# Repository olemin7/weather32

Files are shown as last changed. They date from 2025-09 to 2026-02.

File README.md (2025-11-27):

weather stantion
redused CPU frequency to 80
# Troubleshooting

* Program upload failure

    * Hardware connection is not correct: run `idf.py -p PORT monitor`, and reboot your board to see if there are any output logs.
    * The baud rate for downloading is too high: lower your baud rate in the `menuconfig` menu, and try again.

https://esp-idf-lib.readthedocs.io/en/latest/groups/bmp180.html

https://github.com/espressif/esp-iot-solution

# esp32c3_supermini
    Pin     | ADC | func |
GPIO_NUM_0  | A0  |      |photoresistor
GPIO_NUM_1  | A1  |      |service switch
GPIO_NUM_2  | A2  |      |
GPIO_NUM_3  | A3  |      |
GPIO_NUM_4  | A4  | SCK  | 
3V3
GND
5V
-------------------------------------
GPIO_NUM_5  | A5  | MISO |
GPIO_NUM_6  |     | MOSI | bme680 SDA !!! swap in new PCB version
GPIO_NUM_7  |     | SS   | bme680 SDL
GPIO_NUM_8  |     | SDA  | LED           
GPIO_NUM_9  |     | SDL  | BOOT_BUTTON   
GPIO_NUM_10 |     |      |
GPIO_NUM_20 |     | RX   |
GPIO_NUM_21 |     | TX   |

https://github.com/DiegoPaezA/ESP32-freeRTOS/blob/master/i2c_scanner/main/i2c_scanner.c
https://github.com/espressif/esp-iot-solution/tree/dd15770d0f8c5fedea78809737f04b63d3765c83/examples/sensors/sensor_hub_monitor

. /home/oleksandr/ides/tools/esp-idf-v5.3/export.sh
export IOT_SOLUTION_PATH=/home/oleksandr/personal/repo/esp-iot-solution
idf.py set-target esp32c3
idf.py build
idf.py menuconfig

null in the env https://github.com/espressif/idf-eclipse-plugin/issues/535https://components.espressif.com/

Check the values in your sdkconfig for LOG_MAXIMUM_LEVEL. It defaults to matching LOG_DEFAULT_LEVEL which limits what values you can use by default.

# mqtt test
sudo apt-get install mosquitto mosquitto-clients

sudo vim /etc/mosquitto/mosquitto.conf 
add
  listener 1883 0.0.0.0
  allow_anonymous true

sudo ufw allow 1883

sudo /etc/init.d/mosquitto restart

mosquitto_sub -h nas.local -d -t advertisement
mosquitto_pub -h nas.local -d -t cmd -m "adv"
mosquitto_sub -h 192.168.1.2 -d -t devices/64E833880880/#

one terminal
mosquitto_sub -d -t hello/world
mosquitto_sub -d -t stat/weather -h central.local
Connect to another ssh session and run
mosquitto_pub -d -t hello/world -m "Hello from terminal window 2!"

sudo tail -f /var/log/mosquitto/mosquitto.log

mosquitto_sub -h nas.local -d -t '#'
https://github.com/nopnop2002/esp-idf-json/tree/master/json-basic-object

# button
todo boot btn to go provision mode?

# esp-idf-lib
https://esp-idf-lib.readthedocs.io/en/latest/index.html
git clone git@github.com:UncleRus/esp-idf-lib.git

# dependency
https://github.com/olemin7/esp32_idf_libs

# TP4056  li ion charger
max 4.2
min 2.5
## li ion
max 4.2
min 3.0

## attenuation
ADC_ATTEN_DB_0   100 mV ~ 950 mV
ADC_ATTEN_DB_2_5 100 mV ~ 1250 mV
ADC_ATTEN_DB_6   150 mV ~ 1750 mV
ADC_ATTEN_DB_12  150 mV ~ 2450 mV

https://docs.espressif.com/projects/esp-idf/en/v4.4.8/esp32/api-reference/peripherals/adc.html
#photoresistor (GND ) -photoresistor- (A0) -resistor 10k- (+3.3)

# LiIon
min 
https://esp32tutorials.com/esp32-esp-idf-max7219-dot-matrix-display

[json]
https://github.com/nopnop2002/esp-idf-json

# cmd list
export TARGET_MAC=64E833885558
export TARGET_MAC=64E833880880
export TARGET_MAC=64E83387D7D0
export TARGET_MAC=64E8338811DC
mosquitto_sub -d -t response/$TARGET_MAC -h nas.local
mosquitto_sub -d -t devices/$TARGET_MAC/# -h nas.local

mosquitto_pub -d -t cmd/$TARGET_MAC -m '{"cmd":"help"}' -h nas.local

mosquitto_pub -d -t cmd/$TARGET_MAC -m '{"cmd":"ldr","payload":{"min":100,"max":3000}}' -h nas.local
mosquitto_pub -d -t cmd/$TARGET_MAC -m '{"cmd":"restart"}' -h nas.local

mosquitto_pub -d -t cmd/$TARGET_MAC -m '{"cmd":"brightness","payload":{"points":[{"lighting":1530,"brightness":10}]}}' -h nas.local

mosquitto_pub -d -t cmd/$TARGET_MAC -m -h nas.local '{"cmd":"brightness","payload":{"points":[{"lighting":1530,"brightness":10}]}}' 

{"cmd":"display","payload":{"segment_rotation":0,"segment_upsidedown":false,"mirrored":false}}

'{"cmd":"display","payload":{"segment_rotation":3,"segment_upsidedown":true,"mirrored":true}}

'{"cmd":"timezone","payload":{"tz":"GMT-3"}}'

[http command server]
url /cmd
smd the same as for mosqitoo
[IDF_PATH]

printenv IDF_PATH

export IDF_PATH="/home/oleksandrminenko/personal/esp-idf/v5.4/esp-idf"

[TODO]
custom data when provision

[test]
https://www.throwtheswitch.org/unity
idf.py -p /dev/ttyACM0 flash

[mink]
long press on boot btn ->reprovision

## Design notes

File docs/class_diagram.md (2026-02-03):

# Weather Station Class Diagram

```mermaid
classDiagram
    class app_main {
        -unique_ptr~CMQTTWrapper~ mqtt_mng
        -unique_ptr~bme680_sensor~ bme680_p
        -unique_ptr~bh1750_sensor~ bh1750_p
        -unique_ptr~adc_sensor~ adc_p
        -unique_ptr~ESPTimer~ sleep_timer
        -map~string,string~ sensors_data
        -EventGroupHandle_t app_main_event_group
        -chrono_seconds deep_sleep_duration
        +init()
        +sensors_off()
        +shootdown()
        +collect_sensors_data(field, value)
        +event_got_ip_handler()
    }

    class CMQTTWrapper {
        -device_info_t device_info_
        -Filter device_cmd_
        -Filter brodcast_cmd_
        -unique_ptr~command_cb_t~ device_cmd_cb_
        -unique_ptr~all_send_cb_t~ all_send_cb_
        -unique_ptr~connection_state_cb_t~ connection_state_cb_
        -set~MessageID~ send_mgs_list_
        +CMQTTWrapper(device_info, cmd_cb, state_cb)
        +publish(topic, message)
        +publish_device_brunch(field, value)
        +is_all_send()
        +is_all_send_cb(callback)
        -on_connected(event)
        -on_disconnected(event)
        -on_published(event)
        -on_data(event)
        -send_advertisement()
    }

    class device_info_t {
        +string sw
        +string ip
        +string mac
    }

    class generic_cb~T~ {
        <<abstract>>
        #getter_t~T~ getter_
        #on_success_cb_t~T~ on_success_
        #on_error_cb_t on_error_
        #const char* tag_
        +generic_cb(tag, getter, on_success, on_error)
    }

    class timed_cb~T~ {
        #int retry_
        #unique_ptr~ESPTimer~ timer_p_
        +timed_cb(tag, getter, on_success, on_error, start_delay, retry, retry_timeout)
    }

    class bme680_sensor {
        -unique_ptr~timed_cb~sensor_value_t~~ handler_
        -bme680_t dev_
        +sensor(on_success, on_error)
        +~sensor()
        -get_value(value) bool
    }

    class bh1750_sensor {
        -unique_ptr~timed_cb~sensor_value_t~~ handler_
        -i2c_dev_t dev_
        +sensor(on_success, on_error)
        +~sensor()
        -get_value(value) bool
    }

    class adc_sensor {
        -uint8_t fails_in_row_
        -unique_ptr~ESPTimer~ timer_p_
        -average~sensor_value_t~ average_
        -adc_oneshot_unit_handle_t adc_handle_
        +sensor(on_success, on_error)
        +~sensor()
        -get_value(value) bool
    }

    class average~T_S~ {
        #const uint8_t capacity_
        #queue~T~ queue_
        #S summ_
        +average(capacity)
        +push(value)
        +get_size() T
        +get_capacity() uint16_t
        +get_average() T
    }

    class average_treshold~T_S~ {
        -const T treshold_
        -T prev_
        +average_treshold(treshold, deep)
        +push(value) bool
        #re_arm()
    }

    class average_treshold_timeout~T_S~ {
        -const chrono_milliseconds keep_alive_
        -chrono_time_point next_
        +average_treshold_timeout(treshold, deep, keep_alive)
        +push(value) bool
    }

    class ESPTimer {
        +start(duration)
        +stop()
    }

    class kvs_handler {
        -unique_ptr~NVSHandle~ handle_
        -bool updated_
        +handler(ns_name)
        +get_value(key, value)
        +set_value(key, value)
        +get_value_or(key, value, default)
        -set_item_(key, value)
    }

    class blink {
        <<namespace>>
        +init()
        +start(state)
        +stop(state)
    }

    class provision {
        <<namespace>>
        +provision_main()
        +provision_reset()
    }

    class deepsleep {
        <<namespace>>
        +get_boot_count() uint32_t
        +sleep(duration)
    }

    class utils {
        <<namespace>>
        +get_mac() string
        +to_Str(ip) string
        +print_info()
        +transform_range(in_min, in_max, out_min, out_max, value) T
    }

    timed_cb --|> generic_cb : inherits
    average_treshold --|> average : inherits
    average_treshold_timeout --|> average_treshold : inherits
    adc_sensor --|> generic_cb : inherits

    app_main --> CMQTTWrapper : creates
    app_main --> bme680_sensor : creates
    app_main --> bh1750_sensor : creates
    app_main --> adc_sensor : creates
    app_main --> ESPTimer : creates
    app_main --> provision : calls
    app_main --> deepsleep : calls
    app_main --> blink : calls
    app_main --> utils : calls

    CMQTTWrapper --> device_info_t : contains

    bme680_sensor --> timed_cb : contains
    bh1750_sensor --> timed_cb : contains
    adc_sensor --> ESPTimer : contains
    adc_sensor --> average : contains

    timed_cb --> ESPTimer : contains
```

## Key Classes

### Main Application
- **app_main**: Entry point, orchestrates sensors, MQTT, and deep sleep
  - Event flags: GOT_IP, GOT_SENSOR_DATA, GOT_LIGHTING_DATA, GOT_BAT, MQTT_EMPTY
  - Manages deep_sleep_duration (normal or low battery mode)

### MQTT Communication
- **CMQTTWrapper**: MQTT client wrapper for publishing sensor data
- **device_info_t**: Device identification (MAC, IP, SW version)

### Sensor Base Classes
- **generic_cb<T>**: Abstract base with getter, success/error callbacks
- **timed_cb<T>**: Extends generic_cb with timer and retry logic
  - Used by BME680 and BH1750 sensors

### Sensors
- **bme680::sensor**: Temperature, humidity, pressure (I2C)
  - sensor_value_t = bme680_values_float_t
  - Uses timed_cb for periodic reads
- **bh1750::sensor**: Light intensity (I2C)
  - sensor_value_t = uint16_t (lux)
  - Uses timed_cb for periodic reads
- **adc::sensor**: Battery voltage (ADC_CHANNEL_0)
  - sensor_value_t = int
  - Inherits from generic_cb
  - Uses ESPTimer + average for smoothing
  - Tracks fails_in_row (max: CONFIG_ADC_MAX_FAILS_IN_ROW)

### Utilities
- **average<T,S>**: Rolling average with fixed capacity queue
- **average_treshold<T,S>**: Extends average, triggers on threshold change
- **average_treshold_timeout<T,S>**: Adds keep-alive timeout
- **ESPTimer**: Timer wrapper (idf::esp_timer::ESPTimer)
- **kvs::handler**: Key-value storage (NVS) wrapper
- **blink**: LED indicator control (namespace)
- **provision**: WiFi provisioning (namespace)
- **deepsleep**: Deep sleep management (namespace)
- **utils**: Helper functions (namespace)

## Relationships

- app_main creates unique_ptr instances of all sensors and MQTT
- BME680/BH1750 use timed_cb (inherits generic_cb) for async reads
- ADC sensor inherits generic_cb directly, uses ESPTimer + average
- All sensors invoke callbacks on success/error
- CMQTTWrapper publishes collected sensor data to MQTT broker
- ESPTimer provides timeout protection (sleep_timer in app_main)
- Sensors destroyed via sensors_off() before deep sleep

## Memory Management

- All major objects use std::unique_ptr for automatic cleanup
- Sensors destroyed before deep sleep to save power
- MQTT wrapper destroyed after all messages sent

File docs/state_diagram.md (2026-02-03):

# Weather Station State Diagram

```mermaid
stateDiagram-v2
    [*] --> Init: Power On/Wake from Deep Sleep
    
    Init --> CheckBootCount: Initialize I2C, sensors, GPIO, event loop
    
    CheckBootCount --> CheckServiceSwitch: First boot (count=0)
    CheckBootCount --> Provision: Not first boot
    
    CheckServiceSwitch --> FactoryReset: GPIO_1 LOW
    CheckServiceSwitch --> Provision: GPIO_1 HIGH
    
    FactoryReset --> [*]: Reset & Restart
    
    Provision --> StartSensors: WiFi provisioning complete
    
    StartSensors --> WaitingForData: Start timeout timer
    
    state WaitingForData {
        [*] --> CollectingSensors
        CollectingSensors --> BME680Ready: GOT_SENSOR_DATA
        CollectingSensors --> BH1750Ready: GOT_LIGHTING_DATA
        CollectingSensors --> ADCReady: GOT_BAT
        
        BME680Ready --> AllDataReady: Check all bits
        BH1750Ready --> AllDataReady: Check all bits
        ADCReady --> AllDataReady: Check all bits
        
        note right of ADCReady
            If bat < CONFIG_DEEP_SLEEP_LOWBAT:
            Set deep_sleep_duration to
            CONFIG_DEEP_SLEEP_LOWBAT_DURATION_S
        end note
    }
    
    WaitingForData --> SensorsOff: All sensor data collected
    
    SensorsOff --> WaitingForIP: Power down BME680, BH1750, ADC
    
    state WaitingForIP {
        [*] --> WiFiConnecting
        WiFiConnecting --> IPObtained: GOT_IP
        IPObtained --> MQTTInit: Create MQTT wrapper
        MQTTInit --> ReadRSSI: Get WiFi signal strength
    }
    
    WaitingForIP --> MQTTPublish: MQTT ready
    
    MQTTPublish --> WaitingForMQTT: Publish all sensor data
    
    state MQTTPublish {
        [*] --> PublishSensors
        PublishSensors --> PublishRSSI
        PublishRSSI --> PublishSleep
        PublishSleep --> [*]
        
        note left of PublishSensors
            temperature, humidity, pressure,
            lux, bat_percentage, adc, rssi
        end note
    }
    
    WaitingForMQTT --> Shutdown: MQTT_EMPTY
    
    Shutdown --> DeepSleep: Stop & restart timer (0s)
    
    DeepSleep --> [*]: Sleep for deep_sleep_duration
    
    note right of StartSensors
        Timeout timer: CONFIG_DEEP_SLEEP_TIMEOUT_S
        Triggers shootdown() on expiry
    end note
    
    note right of DeepSleep
        Normal: CONFIG_DEEP_SLEEP_DURATION_S
        Low Battery: CONFIG_DEEP_SLEEP_LOWBAT_DURATION_S
    end note
    
    state "Timeout Handler" as Timeout
    WaitingForData --> Timeout: Timer expires
    WaitingForIP --> Timeout: Timer expires
    WaitingForMQTT --> Timeout: Timer expires
    Timeout --> Shutdown: shootdown()
```

## Event Flags

- **GOT_IP**: WiFi connected and IP obtained (BIT0)
- **GOT_SENSOR_DATA**: BME680 temperature/humidity/pressure data ready (BIT1)
- **GOT_LIGHTING_DATA**: BH1750 light sensor data ready (BIT2)
- **GOT_BAT**: ADC battery voltage data ready (BIT3)
- **MQTT_EMPTY**: All MQTT messages sent (BIT4)

## Sensors

- **BME680**: Temperature, humidity, pressure sensor (I2C)
- **BH1750**: Light sensor (I2C)
- **ADC**: Battery voltage monitoring (ADC_CHANNEL_0, GPIO_NUM_0)

## Key States

1. **Init**: Initialize I2C (i2cdev_init), event loop, GPIO, create sensors
2. **CheckBootCount**: Check deepsleep::get_boot_count() == 0 for first boot
3. **CheckServiceSwitch**: Check GPIO_1 level for factory reset (LOW = reset)
4. **Provision**: WiFi provisioning via provision_main()
5. **StartSensors**: Start timeout timer (CONFIG_DEEP_SLEEP_TIMEOUT_S)
6. **WaitingForData**: Parallel sensor data collection via callbacks
7. **SensorsOff**: Destroy sensor objects (bme680_p, bh1750_p, adc_p)
8. **WaitingForIP**: Wait for IP_EVENT_STA_GOT_IP event
9. **MQTTPublish**: Publish collected data (temperature, humidity, pressure, lux, bat_percentage, adc, rssi, sleep)
10. **Shutdown**: Stop timer, call shootdown() → deepsleep::sleep()
11. **DeepSleep**: Enter low-power mode for deep_sleep_duration

## Data Collection

Sensor data is collected via callbacks into `sensors_data` map:
- BME680: temperature, humidity, pressure
- BH1750: lux
- ADC: bat_percentage (transformed from CONFIG_BATTERY_MIN/MAX), adc raw value
- WiFi: rssi (signal strength)
- System: sleep duration

## Low Battery Handling

If battery percentage < CONFIG_DEEP_SLEEP_LOWBAT:
- deep_sleep_duration changes from CONFIG_DEEP_SLEEP_DURATION_S to CONFIG_DEEP_SLEEP_LOWBAT_DURATION_S

## Timeout Protection

A watchdog timer (sleep_timer) runs for CONFIG_DEEP_SLEEP_TIMEOUT_S. If any state takes too long, shootdown() is called, forcing sensors off and entering deep sleep.

## GPIO Configuration

- **GPIO_NUM_1**: Service switch (input, pull-up enabled)
  - LOW on first boot → Factory reset
  - HIGH → Normal operation

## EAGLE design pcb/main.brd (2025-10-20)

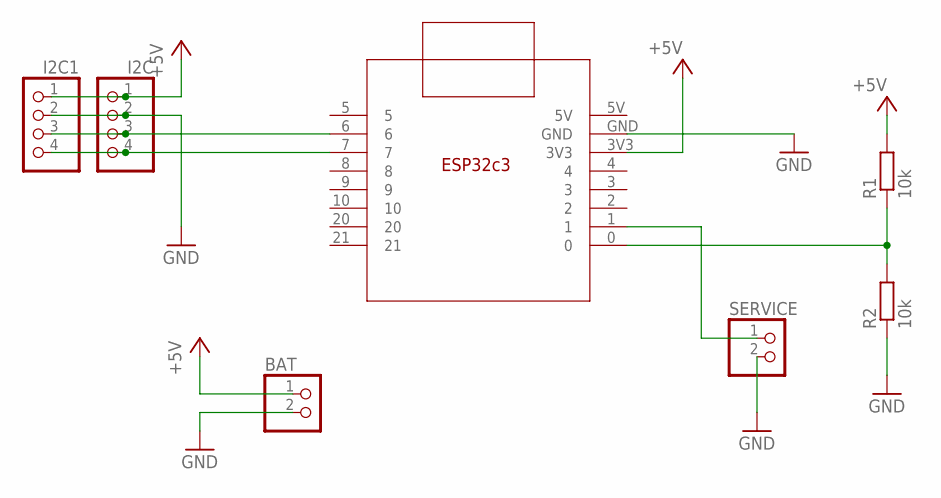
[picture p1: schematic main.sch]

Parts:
BAT: PINHD-1X2; 1X02
I2C, I2C1: PINHD-1X4; 1X04
R1, R2: 10k; R0805
SERVICE: PINHD-1X2; 1X02
U$2: ESP32C3SMD; ESP32C3_SMD

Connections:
+5V: BAT.1, I2C.1, I2C1.1, R1.2, U$2.3V3
GND: BAT.2, I2C.2, I2C1.2, R2.1, SERVICE.2, U$2.GND
unnamed: I2C.3, I2C1.3, U$2.6
unnamed: R1.1, R2.2, U$2.0
unnamed: I2C.4, I2C1.4, U$2.7
unnamed: SERVICE.1, U$2.1

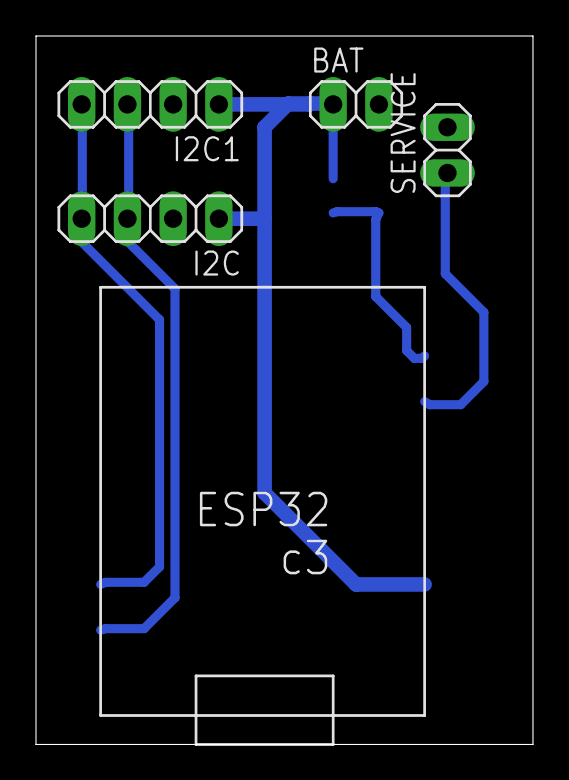
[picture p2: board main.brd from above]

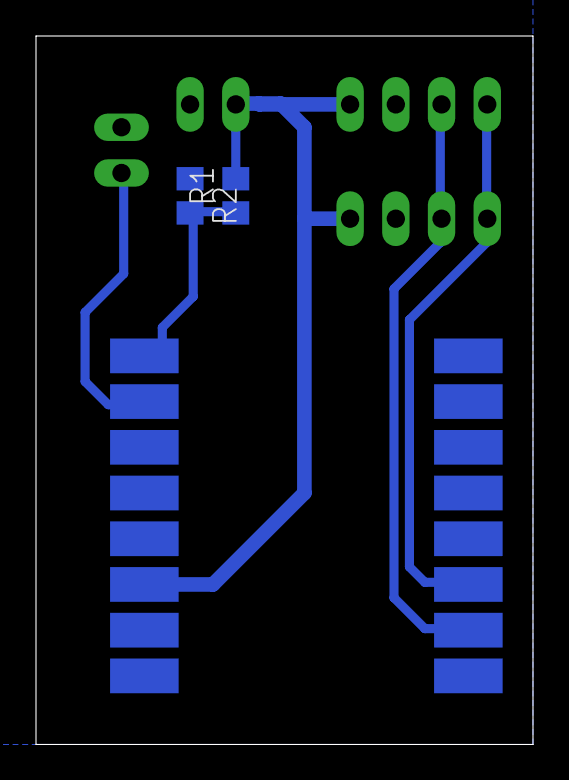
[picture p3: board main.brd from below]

Board: 2 copper layers, 27.6 x 39.4 mm, 7 parts (2 on the bottom side), 6 nets.

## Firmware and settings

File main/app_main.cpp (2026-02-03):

#include <esp_event.h>
#include <esp_log.h>
#include <esp_wifi.h>
#include <inttypes.h>
#include <math.h>
#include <stdio.h>

#include <chrono>
#include <iostream>
#include <map>
#include <memory>
#include <string>

#include "deepsleep.hpp"
#include "display/blink.hpp"
#include "esp_err.h"
#include "esp_exception.hpp"
#include "esp_timer_cxx.hpp"
#include "freertos/FreeRTOS.h"
#include "freertos/queue.h"
#include "freertos/task.h"
#include "iot_button.h"
#include "mqtt_tools/mqtt_wrapper.hpp"
#include "provision/provision.hpp"
#include "rom/rtc.h"
#include "sdkconfig.h"
#include "sensors/adc.hpp"
#include "sensors/bh1750.hpp"
#include "sensors/bme680.hpp"
#include "utils/json_helper.hpp"
#include "utils/kvs.hpp"
#include "utils/utils.hpp"

using namespace std::chrono_literals;
static const char *TAG = "main";

constexpr auto DEVICE_SW = "weather32 "__DATE__
                           " " __TIME__;

std::unique_ptr<mqtt::CMQTTWrapper> mqtt_mng = nullptr;
std::unique_ptr<bme680::sensor> bme680_p = nullptr;
std::unique_ptr<bh1750::sensor> bh1750_p = nullptr;
std::unique_ptr<adc::sensor> adc_p = nullptr;
std::unique_ptr<idf::esp_timer::ESPTimer> sleep_timer = nullptr;
std::map<std::string, std::string> sensors_data = {};

static EventGroupHandle_t app_main_event_group;
constexpr int GOT_IP = BIT0;
constexpr int GOT_SENSOR_DATA = BIT1;
constexpr int GOT_LIGHTING_DATA = BIT2;
constexpr int GOT_BAT = BIT3;
constexpr int MQTT_EMPTY = BIT4;

auto deep_sleep_duration = std::chrono::seconds(CONFIG_DEEP_SLEEP_DURATION_S);

template <typename T>
void collect_sensors_data(const std::string &field, T value)
{
    sensors_data[field] = std::to_string(value);
}

static void event_got_ip_handler(void *arg, esp_event_base_t event_base, int32_t event_id, void *event_data)
{
    mqtt::device_info_t device_info;
    ip_event_got_ip_t *event = (ip_event_got_ip_t *)event_data;
    device_info.ip = utils::to_Str(event->ip_info.ip);

    ESP_LOGI(TAG, "Connected with IP Address: %s", device_info.ip.c_str());

    /* Signal main application to continue execution */
    xEventGroupSetBits(app_main_event_group, GOT_IP);

    device_info.sw = DEVICE_SW;
    device_info.mac = utils::get_mac();

    mqtt_mng = std::make_unique<mqtt::CMQTTWrapper>(device_info, nullptr,
                                                    std::make_unique<mqtt::connection_state_cb_t>([](auto connected) {}));
    int rssi = -1;
    if (ESP_OK == esp_wifi_sta_get_rssi(&rssi))
    {
        ESP_LOGI(TAG, "RSSI: %d", rssi);
        collect_sensors_data("rssi", rssi);
    }
    blink::stop(blink::BLINK_CONNECTING);
}

void sensors_off()
{
    ESP_LOGI(TAG, "sensors_off");
    bme680_p.reset();
    bh1750_p.reset();
    adc_p.reset();
}

void shootdown()
{
    ESP_LOGI(TAG, "SHUTDOWN");
    sensors_off();
    ESP_LOGI(TAG, "entering deep sleep ");
    deepsleep::sleep(deep_sleep_duration);
}

void init()
{
    utils::print_info();
    // Create a default event loop
    ESP_ERROR_CHECK(esp_event_loop_create_default());
    app_main_event_group = xEventGroupCreate();
    kvs::init();
    ESP_ERROR_CHECK(i2cdev_init());
    bme680_p = std::make_unique<bme680::sensor>([](auto value)
                                                {

                                                    collect_sensors_data("temperature", value.temperature);
                                                    collect_sensors_data("humidity", value.humidity);
                                                    collect_sensors_data("pressure", value.pressure);
                                                    xEventGroupSetBits(app_main_event_group, GOT_SENSOR_DATA); },

                                                []()
                                                { xEventGroupSetBits(app_main_event_group, GOT_SENSOR_DATA); });
    bh1750_p = std::make_unique<bh1750::sensor>([](auto lux)
                                                {
                                                    collect_sensors_data("lux", lux);
                                                    xEventGroupSetBits(app_main_event_group, GOT_LIGHTING_DATA); },
                                                []()
                                                { xEventGroupSetBits(app_main_event_group, GOT_LIGHTING_DATA); });

    adc_p = std::make_unique<adc::sensor>([](auto value)
                                          { const auto persentage = utils::transform_range<decltype(value), uint8_t>( CONFIG_BATTERY_MIN,CONFIG_BATTERY_MAX,0,100,value);
        ESP_LOGI(TAG, "bat_persentage %d", persentage);
        collect_sensors_data("bat_persentage", persentage);
        collect_sensors_data("adc", value);
        if (CONFIG_DEEP_SLEEP_LOWBAT > persentage)
        {
            ESP_LOGW(TAG, "Low BAT, %u", persentage);
            deep_sleep_duration = std::chrono::seconds(CONFIG_DEEP_SLEEP_LOWBAT_DURATION_S);
        }
                                            xEventGroupSetBits(app_main_event_group, GOT_BAT); },
                                          []()
                                          { xEventGroupSetBits(app_main_event_group, GOT_BAT); });
    sleep_timer = std::make_unique<idf::esp_timer::ESPTimer>([]()
                                                             { 
                                                                ESP_LOGW(TAG, "Timeout");
                                                                shootdown(); });
    /* Initialize TCP/IP */
    ESP_ERROR_CHECK(esp_netif_init());

    /* Initialize the event loop */
    ESP_ERROR_CHECK(esp_event_handler_register(IP_EVENT, IP_EVENT_STA_GOT_IP, &event_got_ip_handler, NULL));

    gpio_config_t io_conf;
    io_conf.intr_type = GPIO_INTR_DISABLE;        // No interrupt
    io_conf.mode = GPIO_MODE_INPUT;               // Set as input
    io_conf.pin_bit_mask = (1ULL << GPIO_NUM_1);  // Select the pin
    io_conf.pull_down_en = GPIO_PULLDOWN_DISABLE; // No pull-down
    io_conf.pull_up_en = GPIO_PULLUP_ENABLE;      // Enable pull-up

    // Apply the configuration
    gpio_config(&io_conf);
    if (deepsleep::get_boot_count() == 0)
    {
        ESP_LOGW(TAG, "The firs boot");
        blink::init();
        if ((gpio_get_level(GPIO_NUM_1) == 0))
        {
            ESP_LOGW(TAG, "Service swith after power reset");
            blink::start(blink::BLINK_FACTORY_RESET);
            wifi_init_config_t cfg = WIFI_INIT_CONFIG_DEFAULT();
            ESP_ERROR_CHECK(esp_wifi_init(&cfg));
            ESP_ERROR_CHECK(provision_reset());
        }
    }
}

/************************************
 *
 */
// #define UNIT_TEST
#ifndef UNIT_TEST
extern "C" void app_main(void)
{
    ESP_LOGI(TAG, "Startup");
    init();
    //------------------------------

    provision_main();
    ESP_LOGI(TAG, "Started");
    sleep_timer->start(std::chrono::seconds(CONFIG_DEEP_SLEEP_TIMEOUT_S));
    //------------------------------

    blink::start(blink::BLINK_CONNECTING);
    xEventGroupWaitBits(app_main_event_group, GOT_SENSOR_DATA | GOT_LIGHTING_DATA | GOT_BAT, pdTRUE, pdTRUE, portMAX_DELAY);
    sensors_off();
    xEventGroupWaitBits(app_main_event_group, GOT_IP, pdTRUE, pdTRUE, portMAX_DELAY);

    if (mqtt_mng)
    {
        ESP_LOGI(TAG, "send sensors data");
        for (const auto &pair : sensors_data)
        {
            mqtt_mng->publish_device_brunch(pair.first, pair.second);
        }
    }
    mqtt_mng->publish_device_brunch("sleep", deep_sleep_duration.count());
    mqtt_mng->is_all_send_cb([]()
                             { xEventGroupSetBits(app_main_event_group, MQTT_EMPTY); });
    xEventGroupWaitBits(app_main_event_group, MQTT_EMPTY, pdTRUE, pdTRUE, portMAX_DELAY);
    ESP_LOGI(TAG, "done");
    sleep_timer->stop();
    sleep_timer->start(0s);
}

#else

#include "unity.h"
void do_tests_utils();

extern "C" void app_main(void)
{
    do_tests_utils();
}
#endif

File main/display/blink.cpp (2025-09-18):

/*
 * blink.cpp
 *
 *  Created on: Jul 1, 2024
 *      Author: oleksandr
 */
#include "blink.hpp"
#include "esp_log.h"
#include "sdkconfig.h"
#include "led_indicator.h"

namespace blink {
    constexpr auto GPIO_LED_PIN = GPIO_NUM_8;
    constexpr auto GPIO_ACTIVE_LEVEL = true;
    static const char *TAG = "led_gpio";

    static led_indicator_handle_t led_handle = NULL;

    /**
     * @brief connecting to AP (or Cloud)
     *
     */
    static const blink_step_t default_connecting[] = {
        {LED_BLINK_HOLD, LED_STATE_ON, 200},
        {LED_BLINK_HOLD, LED_STATE_OFF, 800},
        {LED_BLINK_LOOP, 0, 0},
    };

    /**
     * @brief connected to AP (or Cloud) succeed
     *
     */
    static const blink_step_t default_connected[] = {
        {LED_BLINK_HOLD, LED_STATE_ON, 1000},
        {LED_BLINK_LOOP, 0, 0},
    };

    /**
     * @brief reconnecting to AP (or Cloud), if lose connection
     *
     */
    static const blink_step_t default_reconnecting[] = {
        {LED_BLINK_HOLD, LED_STATE_ON, 100},
        {LED_BLINK_HOLD, LED_STATE_OFF, 200},
        {LED_BLINK_LOOP, 0, 0},
    }; // offline

    /**
     * @brief updating software
     *
     */
    static const blink_step_t default_updating[] = {
        {LED_BLINK_HOLD, LED_STATE_ON, 50},
        {LED_BLINK_HOLD, LED_STATE_OFF, 100},
        {LED_BLINK_HOLD, LED_STATE_ON, 50},
        {LED_BLINK_HOLD, LED_STATE_OFF, 800},
        {LED_BLINK_LOOP, 0, 0},
    };

    /**
     * @brief restoring factory settings
     *
     */
    static const blink_step_t default_factory_reset[] = {
        {LED_BLINK_HOLD, LED_STATE_ON, 200},
        {LED_BLINK_HOLD, LED_STATE_OFF, 200},
        {LED_BLINK_LOOP, 0, 0},
    };

    /**
     * @brief provision done
     *
     */
    static const blink_step_t default_provisioned[] = {
        {LED_BLINK_HOLD, LED_STATE_OFF, 1000},
        {LED_BLINK_STOP, 0, 0},
    };

    /**
     * @brief provisioning
     *
     */
    static const blink_step_t default_provisioning[] = {
        {LED_BLINK_HOLD, LED_STATE_ON, 500},
        {LED_BLINK_HOLD, LED_STATE_OFF, 500},
        {LED_BLINK_LOOP, 0, 0},
    };

    /**
     * @brief LED indicator blink lists, the index like BLINK_FACTORY_RESET defined the priority of the blink
     *
     */
    blink_step_t const *led_indicator_blink_lists[] = {
        default_factory_reset,
        default_updating,
        default_connected,
        default_provisioned,
        default_reconnecting,
        default_connecting,
        default_provisioning,
        NULL,
    };

    void init()
    {
        if (led_handle != NULL)
        {
            ESP_LOGD(TAG, "inited");
            return;
        }
        ESP_LOGD(TAG, "init");
        led_indicator_gpio_config_t gpio_config = {
            .is_active_level_high = GPIO_ACTIVE_LEVEL,
            .gpio_num = GPIO_LED_PIN,
        };

        const led_indicator_config_t config = {
            .mode = LED_GPIO_MODE,
            .led_indicator_gpio_config = &gpio_config,
            .blink_lists = led_indicator_blink_lists,
            .blink_list_num = MAX_,
        };

        led_handle = led_indicator_create(&config);
        assert(led_handle != NULL);
    };

    void start(int state)
    {
        if (led_handle != NULL)
        {
            ESP_LOGI(TAG, "start blink: %d", static_cast<int>(state));
            led_indicator_start(led_handle, static_cast<int>(state));
        }
    }

    void stop(int state)
    {
        if (led_handle != NULL)
        {
            ESP_LOGI(TAG, "stop blink: %d", static_cast<int>(state));
            led_indicator_stop(led_handle, static_cast<int>(state));
        }
    }

} // namespace blink

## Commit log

2025-09-18 initial 2
    [DRILEGEND.CFG, main.brd, main.sch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]
2025-10-09 posising sensors
2025-10-09 adc initial
2025-10-20 change i2c line
    [main.brd, main.sch]
2025-10-25 update sensors boot handling
